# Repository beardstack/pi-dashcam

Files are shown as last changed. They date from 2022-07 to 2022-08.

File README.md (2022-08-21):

# pi-dashcam

This application follows the idea to setup an OpenSource dashcam
that can be run on a low-cost hardware like the Raspberry PI 3 A+
(but also as in my intial approach with a PI Zero).
Main purpose is to have a trustfull software following the requirements
of GDPR rules in Germany (DSGVO) to store data only temporary and save
video chunks only in cases of accidents/emergencies. Data can be stored
either on RPi SD Card or external USB device (automounted).
Triggering of video data storing can also be done via acceleration sensor.

This project comes with a custom camera and rpi case:
- there is a camera case for the RPi Camera V2 (e.g. NoIR edition)
- there is a RPi 3A+ fitting base, where an RTC-DS3231 can be inserted into
- there is a top covering case, where a breadboard plate of 5x7cm can be easily inserted
    (watch for the LED and Button cutouts!)

I created my own HAT for the Pi-3A+; pictures will follow...

## Requirements
- 32-Bit Raspberry Pi OS (necessary to run picamera v1!)
- min. 1 CPU
- min. 128MB RAM
- Pi Camera attached
- legacy camera support enabled in raspi-config
- RealTime-Clock RTC DS3231 (e.g.: https://www.amazon.de/dp/B077XN4LL4/ref=pe_27091401_487024491_TE_item )
- ADXL345 acceleration sensor (e.g.: https://www.amazon.de/dp/B09T376QXX/ref=pe_27091401_487027711_TE_SCE_dp_1 )
- 4 Buttons and one RGB-LED (e.g.: on amazon, the 12mm x 12mm x 7mm tactile push botton with 5 colours ...)
- 3D printed cases for camera and rpi from 3dprints subfolder
    (and obviously a 3dprinter or you know somebody ;) )
- Some Dashcam carrier for your car (e.g.: https://www.amazon.de/dp/B091BVDT56/ref=pe_27091401_487024491_TE_item )

A single core and 512MB of RAM is sufficient enough to have a 1080p 
dashcam running. However, I decided to stick to the Pi 3A+ in order to be
more powerfull for future approaches.
For a nicer interaction, this application allows the usage of buttons
to e.g. trigger a copy of all legal files at the moment (by default, the last
10 minutes) to a separate folder on the disk (or external, auto-mounted device),
to be available later.
In addition, three LEDs (or an RGB-LED) can be controlled; one is a Power-LED,
that indicates a running system (by default a slow heartbeat pulsar, can be adjusted via Button)
next to a Data-Copy-LED, that lights up when current legal video chunks are stored separately
and blinks for some seconds when that process is done, and finally an info LED
that e.g. shows, no external device mounted or the video capturing process stopped.

More parameter can be set (e.g. resolution, chunk size and count), but the
default values should optimal for the most cases (1080p, 10 video chunks of 60s).

Real-World approach is then to solder all com

For any question, do not hesitate to contact me.

Best regards,
Lars

___________________________
Default PIN scheme:

GND <--> Button Power            <--> Board Pin 11 (GPIO 17)

GND <--> Button Copy             <--> Board Pin 12 (GPIO 18)

GND <--> Button Stop             <--> Board Pin 13 (GPIO 27)

GND <--> Button Info control     <--> Board Pin 15 (GPIO 22)

GND <--> 220R <--> LED Data Copy <--> Board Pin 29 (GPIO 27)

GND <--> 220R <--> LED Power     <--> Board Pin 33 (GPIO 13)

GND <--> 220R <--> LED Power     <--> Board Pin 37 (GPIO 26)

ADXL345 VCC/3V3 <--> Board Pin 1 (3V3)

ADXL345 GND     <--> Board Pin 9 (GND)

ADXL345 CS      <--> Board Pin 24 (GPIO 8 / SPIO CE0)

ADXL345 SD0     <--> Board Pin 21 (GPIO 9 / SPIO MISO)

ADXL345 SDA     <--> Board Pin 19 (GPIO 10 / SPIO MOSI)

ADXL345 SCL     <--> Board Pin 23 (GPIO 11 / SPIO SCLK)

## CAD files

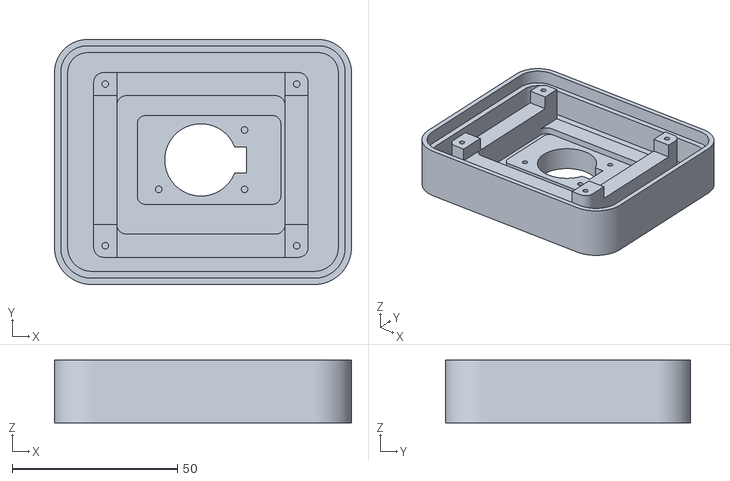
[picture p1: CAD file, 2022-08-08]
3dprints/Dashcam_Picase-Bottom.stl
90.0 x 74.2 x 19.0

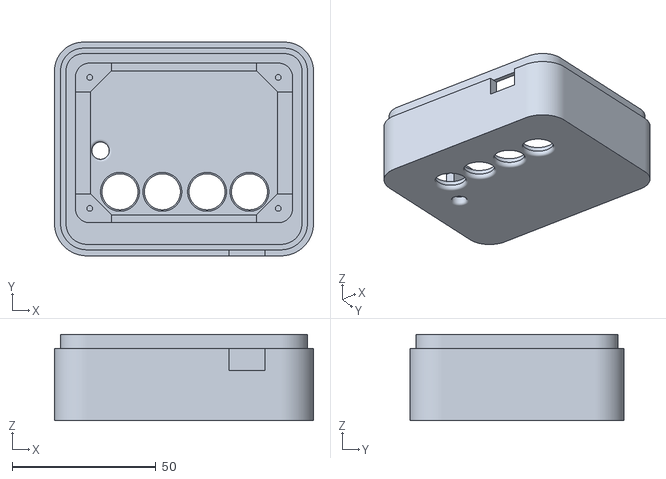
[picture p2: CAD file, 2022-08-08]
3dprints/Dashcam_Picase-Top.stl
90.0 x 74.2 x 30.0

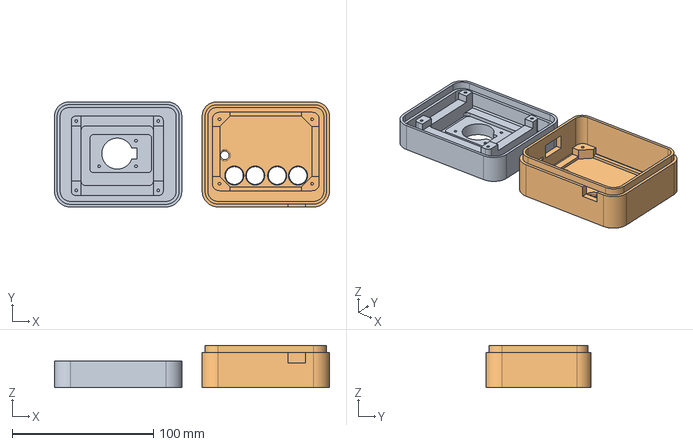
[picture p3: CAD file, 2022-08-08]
3dprints/Dashcam_Picase.FCStd
194.4 x 74.3 x 30.0 mm
Bottom
Top

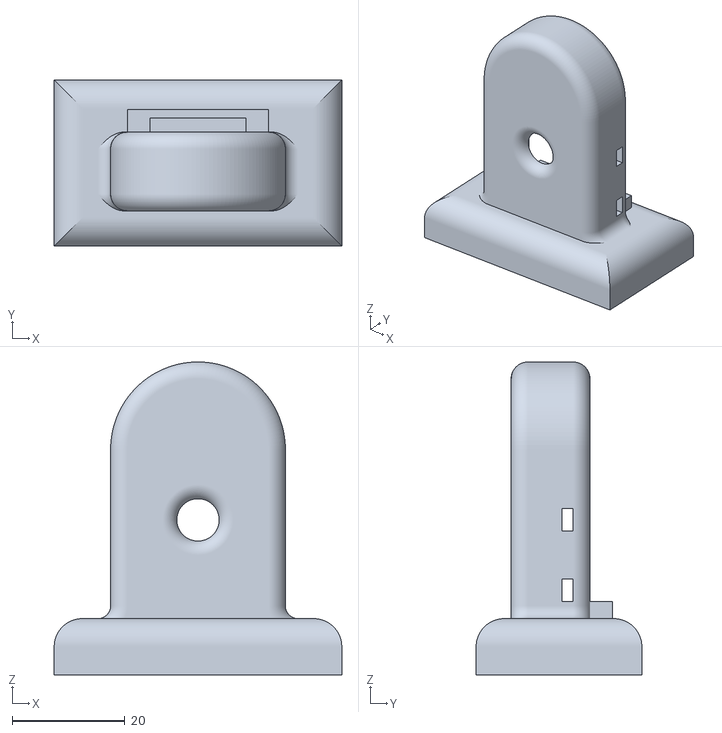
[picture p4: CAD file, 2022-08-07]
3dprints/PiCam_BaseCase.stl
51.0 x 29.4 x 55.5

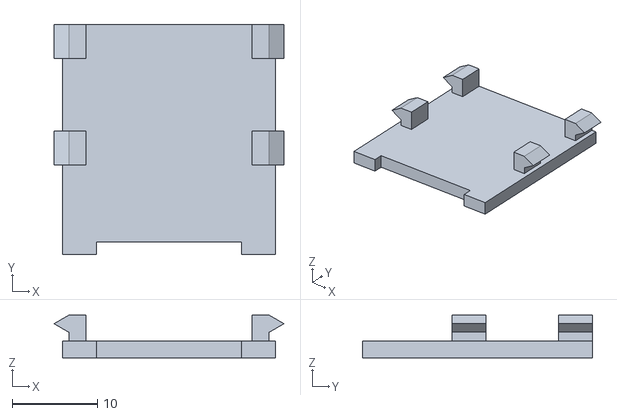
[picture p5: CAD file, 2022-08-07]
3dprints/PiCam_BaseCaseCover.stl
27.0 x 27.0 x 5.00

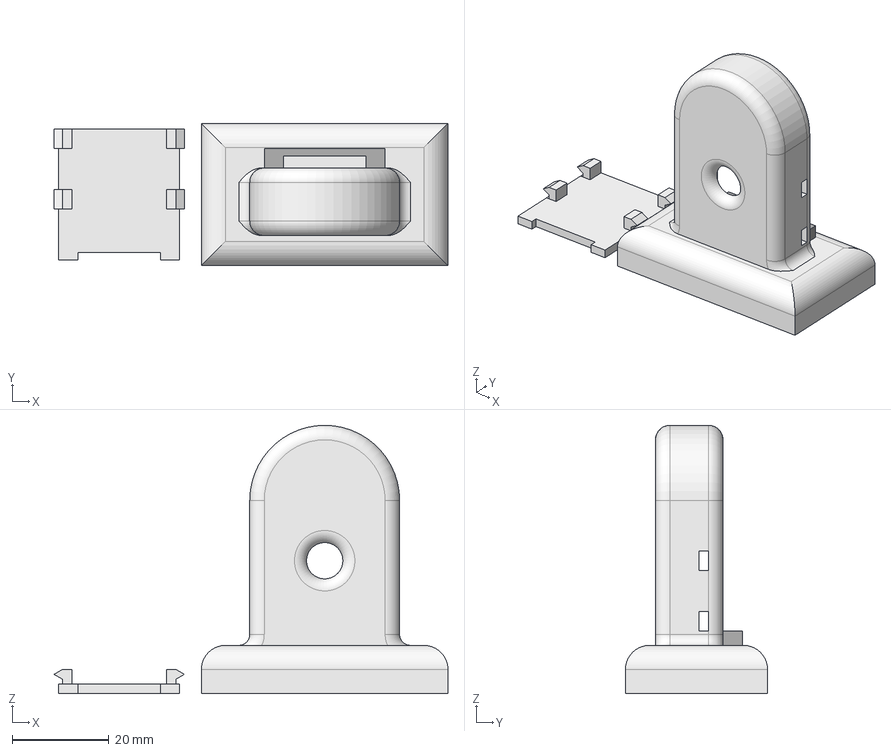
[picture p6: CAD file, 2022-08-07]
3dprints/Dashcam_Picamcase.FCStd
81.5 x 29.4 x 55.5 mm
Base
CameraCase
CameraNotch
Cover001
Hold
Hold001

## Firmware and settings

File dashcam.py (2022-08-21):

#!/usr/bin/env python3
import os
import shutil
import argparse
import picamera
from led import LED
from switch import Switch
from time import time, sleep
from threading import Thread, Lock
from random import randbytes
from movement import Adxl345Spi
from math import fabs


def get_usb_storage_device(desired_device=None):
    with open("/proc/partitions") as file:
        file.readline() #skip heading line
        file.readline() #skip empty line
        device_info = [
            [ item.strip() for item in line.strip().split() ]
            for line in file
        ]
        devices = [
            device[3]
            for device in device_info
            if len(device) >= 3 and device[0] in ("8", "259")
        ]
        primary_devices = [
            device[3]
            for device in device_info
            if len(device) >= 3 and device[0] in ("8", "259") and (int(device[1]) % 16) == 0
        ]

        block_class_path = "/sys/class/block"

        primary_usb_devices = [
            device
            for device in primary_devices
            if (
                os.path.islink(f"{block_class_path}/{device}") and
                os.path.realpath(f"{block_class_path}/{device}").find("/usb") > 0
            )
        ]

        usb_partitions = sorted(
            [
                partition
                for partition in devices
                for usb_device in primary_usb_devices
                if partition.startswith(usb_device) and usb_device != partition
            ],
            reverse=True #assuming the last partition of the last is correct
        )

        if desired_device is not None:
            if desired_device in usb_partitions:
                return desired_device
            return None
        return usb_partitions[0]

def mount_usb_device(device, id):
    mnt_path = f"/mnt/{id}"
    if not os.path.ismount(mnt_path):
        os.system(f"mkdir -p {mnt_path}")
        os.system(f"mount {device} {mnt_path}")
    return mnt_path



class Dashcam():
    def __init__(
            self, sequence_count=10, sequence_length=60, resolution=(1920, 1080),
            video_type="h264", video_name_prefix="video-dashcam", bitrate = 17000000,
            framerate=30, video_file_path="/opt/dashcam", pin_btn_pwr=11, pin_btn_cpy=12,
            pin_btn_stop=13, pin_btn_info=15, pin_led_cpy=29, pin_led_pwr=33,
            pin_led_info=37, led_pwr_dim_perc=5, g_force_limit=1.5, salt_bytes=4):
        self.pin_btn_cpy = pin_btn_cpy
        self.pin_btn_pwr = pin_btn_pwr
        self.pin_btn_info = pin_btn_info
        self.pin_btn_stop = pin_btn_stop
        self.pin_led_pwr = pin_led_pwr
        self.pin_led_cpy = pin_led_cpy
        self.pin_led_info = pin_led_info
        self.pin_led_pwr_dim_percent = led_pwr_dim_perc
        self.pin_blink_seconds = 2
        self.pin_blink_on_seconds = 0.1
        self.g_force_limit = g_force_limit

        self.video_sequence_seconds = sequence_length
        self.video_sequence_count = sequence_count
        self.video_resolution = resolution
        self.video_name_prefix = video_name_prefix
        self.video_file_path=video_file_path
        self.video_file_path_legal=f"{self.video_file_path}/legal"
        self.video_type = video_type if video_type in ("h264", "mjpeg") else "h264"
        self.video_bit_rate = bitrate
        self.video_frame_rate = framerate

        # using a salt to not eventually overwrite files
        # after an unexpected reboot in car; is like
        # a unique identifier for an ongoing record session
        self.video_name_salt = randbytes(salt_bytes).hex()

        self.LED_data = LED(self.pin_led_cpy)
        self.LED_power = LED(self.pin_led_pwr)
        self.LED_info = LED(self.pin_led_info)


        self.BTN_data = Switch(self.pin_btn_cpy)
        self.BTN_power = Switch(self.pin_btn_pwr)
        self.BTN_stop = Switch(self.pin_btn_stop)
        self.BTN_info = Switch(self.pin_btn_info)

        self.file_lock = Lock()
        self.camera_lock = Lock()

        self.adxl345 = Adxl345Spi()

        self.camera = picamera.PiCamera(
            resolution=self.video_resolution,
            framerate=self.video_frame_rate
        )
        self.camera_state = 0 #0: off, 1: turndown, 2: on
        self.info_led_state = 0
        self.segment_ctr = 0
        self.video_filename = ""

    def get_video_id(self):
        return self.video_name_salt

    def set_video_path(self, path):
        self.video_file_path = path
        self.video_file_path_legal = f"{self.video_file_path}/legal"

    def __del__(self):
        del self.LED_data, self.LED_power

    def _dashcam_video_thread(self):
        self.video_filename = (
            f"{self.video_name_prefix}_"
            f"{int(time())}-{self.video_name_salt}-"
            f"{self.segment_ctr}.{self.video_type}"
        )
        video_path = f"{self.video_file_path}/{self.video_filename}"
        print(f"Recording to '{video_path}'.")
        self.camera.start_recording(
            video_path, format=self.video_type, bitrate=self.video_bit_rate
        )
        self.camera.wait_recording(self.video_sequence_seconds)

        while self.camera_state > 1:
            self.segment_ctr += 1
            tmp_video_filename = (
                f"{self.video_name_prefix}_"
                f"{int(time())}-{self.video_name_salt}-"
                f"{self.segment_ctr}.{self.video_type}"
            )
            video_path = f"{self.video_file_path}/{tmp_video_filename}"
            print(f"Recording to '{video_path}'.")
            self.camera.split_recording(video_path)
            # as the copy thread callback might be a bit too fast,
            # we manage to set the final new filename AFTER the switch
            # which guarantees, that the file is really finished.
            self.video_filename = tmp_video_filename
            self.camera.wait_recording(self.video_sequence_seconds)
        self.camera.stop_recording()
        self.camera_state = 0


    def _dashcam_file_cleanup_thread(self):
        while True:
            self.file_lock.acquire()

            video_file_list = self.get_directory_file_list(
                self.video_file_path, self.video_type
            )
            video_file_list_legal = self.get_video_file_list_legal(
                video_file_list, buffer=1
            )

            delete_video_file_list = [
                video_file
                for video_file in video_file_list
                if video_file not in video_file_list_legal
            ]

            for del_video_file in delete_video_file_list:
                print(f"DELETE file '{del_video_file}'")
                try:
                    os.remove(f"{self.video_file_path}/{del_video_file}")
                except FileNotFoundError:
                    print(
                        f"WARNING! File '{self.video_file_path}/{del_video_file}'"
                        " is gone. Ignoreing file. Continue"
                    )

            self.file_lock.release()
            sleep(self.video_sequence_seconds)

    def _led_power_heartbeat(self, LED):
        LED.set_duty_cycle(self.pin_led_pwr_dim_percent)
        sleep(0.15)
        LED.set_duty_cycle(0)
        sleep(0.15)
        LED.set_duty_cycle(self.pin_led_pwr_dim_percent)
        sleep(0.2)
        LED.set_duty_cycle(0)

    def _dashcam_powerled_thread(self):
        round_cntr = 0
        round_time = 0.5

        LED_is_on = True

        LED_state_switch = {
            0: self.LED_info,
            2: self.LED_power
        }

        while True:
            if self.camera_state in LED_state_switch:
                LED = LED_state_switch[self.camera_state]
                if (self.info_led_state % 4) == 0 and (round_cntr % 60) == 0:
                    self._led_power_heartbeat(LED)
                elif (self.info_led_state % 4) == 1 and (round_cntr % 1) == 0:
                    self._led_power_heartbeat(LED)
                elif (self.info_led_state % 4) == 2:
                    if not LED_is_on:
                        LED.set_on()
                        LED.set_duty_cycle(self.pin_led_pwr_dim_percent)
                        LED_is_on = True
                else:
                    if LED_is_on:
                        LED.set_off()
                        LED_is_on = False
            elif self.camera_state == 1:
                if not LED_is_on:
                    self.LED_info.set_duty_cycle(self.pin_led_pwr_dim_percent)
                    LED_is_on = True
                else:
                    self.LED_info.set_off()
                    LED_is_on = False
            #sleep to make catch changes in e.g. info led status changes
            sleep(round_time)
            round_cntr += round_time

    def _g_force_surveillance(self):
        for _ in range(5):
            #cleanup at every start/coldstart (like at car ;) )
            x,y,z = self.adxl345.get_acceleration()
            sleep(1)
        while self.camera_state > 0:
            accl_xyz = self.adxl345.get_acceleration()
            if any(
                fabs(val) > self.g_force_limit
                for val in accl_xyz
            ):
                self.save_video_file_legal(self.LED_data)
            sleep(0.5)
        self.adxl345.stop()

    def get_directory_file_list(self, path, filetype):
        return [
            file
            for file in os.listdir(path)
            if (
                os.path.isfile(os.path.join(path,file)) and
                file.endswith(f'.{filetype}')
            )
        ]

    def get_video_file_list_legal(self, video_file_list, reverse=True, buffer=0):
        prefix_match_sorted_reduced_video_fileid_list = sorted(
            [
                file.removeprefix(
                    f"{self.video_name_prefix}_"
                ).removesuffix(
                    f'.{self.video_type}'
                )
                for file in video_file_list
                if file.startswith(f"{self.video_name_prefix}_")
            ], key = (
                lambda x: (
                    f"{int(x.split('-')[1] == self.video_name_salt)}{x}"
                )
            ), reverse=reverse
        )

        return [
                f"{self.video_name_prefix}_{fileid}.{self.video_type}"
                for fileid in prefix_match_sorted_reduced_video_fileid_list
            ][:self.video_sequence_count+buffer]

    def save_video_file_legal(self, LED):
        self.file_lock.acquire()
        LED.set_on()

        video_file_list_legal = self.get_video_file_list_legal(
            self.get_directory_file_list(
                self.video_file_path, self.video_type
            ), reverse=False
        )

        timestamp = int(time())
        legal_path = f"{self.video_file_path_legal}/{timestamp}_utc"
        os.makedirs(legal_path, exist_ok=True)

        current_video = self.video_filename
        is_active_saving = current_video in video_file_list_legal
        if is_active_saving:
            video_file_list_legal.remove(current_video)

        for video_file in video_file_list_legal:
            src = f"{self.video_file_path}/{video_file}"
            dst = f"{legal_path}/INCIDENT_{video_file}"
            print(f"Copy '{src}' to '{dst}'.")
            try:
                shutil.copyfile(src, dst)
            except FileNotFoundError:
                print(f"WARNING! File '{src}' is gone. Ignoreing file. Continue")
        while is_active_saving and self.video_filename == current_video:
            #waiting for current video to finish
            sleep(5)
        if is_active_saving:
            src = f"{self.video_file_path}/{current_video}"
            dst = f"{legal_path}/INCIDENT_{current_video}"
            print(f"Copy '{src}' to '{dst}'.")
            try:
                shutil.copyfile(src, dst)
            except FileNotFoundError:
                print(f"WARNING! File '{src}' is gone. Ignoreing file. Continue")

        print("Copy done.")

        for round in range(int(self.pin_blink_seconds / self.pin_blink_on_seconds)):
            if round % 2 == 0:
                LED.set_on()
            else:
                LED.set_off()
            sleep(self.pin_blink_on_seconds)

        LED.set_off()
        self.file_lock.release()

    def _button_copy_functor(self, input):
        if input == 0:
            self.save_video_file_legal(self.LED_data)

    def _button_start_functor(self, input):
        if input == 0:
            if self.camera_state == 0:
                self.camera_lock.acquire()
                self.camera_state = 2
                self.video_thread = Thread(target=self._dashcam_video_thread)
                self.g_force_thread = Thread(target=self._g_force_surveillance)
                self.video_thread.start()
                self.LED_power.set_duty_cycle(self.pin_led_pwr_dim_percent)
                self.g_force_thread.start()
                sleep(10) #mainly user notification via LED on
                self.camera_lock.release()

    def _button_stop_functor(self, input):
        if input == 0:
            if self.camera_state == 2:
                self.camera_lock.acquire()
                self.camera_state = 1
                self.LED_power.set_off()
                self.video_thread.join()
                self.g_force_thread.join()
                del self.video_thread
                del self.g_force_thread
                self.camera_lock.release()

    def _button_info_functor(self, input):
        if input == 0:
            # in order to keep numbers small and as we probably won't
            # have more than 100 blinking states, lets keep it 0 < x < 100 !
            self.info_led_state = (self.info_led_state + 1) % 100

    def do_warning(self):
        # just blink at info LED!
        # can be used when e.g. mountpoint is unavailable!!!
        for _ in range(10):
            self.LED_info.set_on()
            sleep(0.5)
            self.LED_info.set_off()
            sleep(0.5)


    def start(self):
        os.makedirs(self.video_file_path, exist_ok=True)
        os.makedirs(self.video_file_path_legal, exist_ok=True)

        self.power_led_thread = Thread(target=self._dashcam_powerled_thread)
        self.clean_thread = Thread(target=self._dashcam_file_cleanup_thread)

        self.BTN_data.set_functor(self._button_copy_functor)
        self.BTN_power.set_functor(self._button_start_functor)
        self.BTN_stop.set_functor(self._button_stop_functor)
        self.BTN_info.set_functor(self._button_info_functor)

        self.power_led_thread.start()
        self.clean_thread.start()

        self._button_start_functor(0)

    def join_clean_thread(self):
        self.clean_thread.join()

def main():
    parser = argparse.ArgumentParser(
        description="""DashCam-app following the German traffic and GDPR (DSGVO)
        laws. Is designed to work on any Raspberry PI that provides PiCamera
        library in Python; this fits basically for any 32-Bit driven RPI.
        Mainly used in combination with a RPI Zero W v1.1, which is totally
        sufficient for this purpose.
        Instead of a single, increasing video file, the input video stream is
        splitted into e.g. 60s video chunks; only the last e.g. 10 chunks are kept.
        This allows to have e.g. the last 10 minutes stored but also regularly cleaned
        in order to stay conform towards GDPR.
        There is a special incident procedure: when an attached button is pressed,
        the last e.g. 10 legal video chunks are separately stored and not cleaned
        to e.g. provide some legal information in any case of accident/emergency.
        In addition, two LEDs can be attached to print Power/Heartbeat information
        and to indicate the current, active data copy in any case of accident (this
        will only happen, when you press the button).
        """
    )

    parser.add_argument(
        "-s", "--video_chunk_duration", metavar="S", type=int, required=False,
        default=60, help="Length of a single stored video chunk."
    )
    parser.add_argument(
        "-c", "--video_chunk_count", metavar="C", type=int, required=False,
        default=10, help=(
            "Max. number of sequential video chunks that are stored in parallel"
            "on the disk; this correlates do GDPR laws."
        )
    )
    parser.add_argument(
        "-p", "--video_file_path", metavar="P", type=str, required=False,
        default="/opt/dashcam", help="Location to store dashcam video chunks"
    )
    parser.add_argument(
        "-f", "--video_file_prefix", metavar="F", type=str, required=False,
        default="video-dashcam", help=(
            "Filename prefix for the locally stored video file chunks"
        )
    )
    parser.add_argument(
        "-r", "--video_resolution", metavar="R", nargs=2, type=int, required=False,
        default=(1920, 1080), help="Length of a single stored video chunk."
    )
    parser.add_argument(
        "-br", "--video_bitrate", metavar="BR", type=int, required=False,
        default=7000000, help="Bitrate used to store videos."
    )
    parser.add_argument(
        "-vf", "--video_format", metavar="VF", type=str, required=False,
        default="h264", choices=("h264","mjpeg"),help="File format used to store videos."
    )
    parser.add_argument(
        "-lc", "--pin_led_copy", metavar="PLC", type=int, required=False,
        default=29, help="Pin number in GPIO.BOARD layout for a data-copy LED."
    )
    parser.add_argument(
        "-lp", "--pin_led_power", metavar="PLP", type=int, required=False,
        default=33, help="Pin number in GPIO.BOARD layout for a power LED."
    )
    parser.add_argument(
        "-li", "--pin_led_info", metavar="PLP", type=int, required=False,
        default=37, help="Pin number in GPIO.BOARD layout for an info LED."
    )
    parser.add_argument(
        "-bp", "--pin_button_power", metavar="PBP", type=int, required=False,
        default=11, help="Pin number in GPIO.BOARD layout for a start button."
    )
    parser.add_argument(
        "-bc", "--pin_button_copy", metavar="PBC", type=int, required=False,
        default=12, help="Pin number in GPIO.BOARD layout for a data copy button."
    )
    parser.add_argument(
        "-bs", "--pin_button_stop", metavar="PBS", type=int, required=False,
        default=13, help="Pin number in GPIO.BOARD layout for a stop button."
    )
    parser.add_argument(
        "-bi", "--pin_button_info", metavar="PBI", type=int, required=False,
        default=15, help="Pin number in GPIO.BOARD layout for a info-led control button."
    )
    parser.add_argument(
        "-d", "--pin_power_dim_percent", metavar="LPD", type=int, required=False,
        default=5, help="Percent dim for the Power LED; if it might be to bright."
    )
    parser.add_argument(
        "-g", "--g_force_limit", metavar="G", type=int, required=False, default=1.5,
        help="Threshold in terms of g-Force, when a data copy should be triggered."
    )
    parser.add_argument(
        "--external_usb_storage_device", metavar="DEVICE", type=str, required=False,
        help=(
            "Dev shortcut, e.g. sda1, for a partition/device you want to use as "
            "video storage. Will be directly written on it."
        )
    )

    args = parser.parse_args()

    video_chunk_duration = args.video_chunk_duration
    video_chunk_count = args.video_chunk_count
    video_file_path = args.video_file_path
    video_file_prefix = args.video_file_prefix
    video_resolution = args.video_resolution
    video_bitrate = args.video_bitrate
    video_format = args.video_format
    pin_button_copy = args.pin_button_copy
    pin_button_power = args.pin_button_power
    pin_button_stop = args.pin_button_stop
    pin_button_info = args.pin_button_info
    pin_led_power = args.pin_led_power
    pin_led_copy = args.pin_led_copy
    pin_led_info = args.pin_led_info
    pin_power_dim_percent = args.pin_power_dim_percent
    g_force_limit = args.g_force_limit
    usb_storage = args.external_usb_storage_device if hasattr(args,'external_usb_storage_device') else None


    dashcam = Dashcam(
        sequence_count=video_chunk_count, sequence_length=video_chunk_duration,
        resolution=video_resolution, video_type=video_format, bitrate=video_bitrate,
        video_name_prefix=video_file_prefix, video_file_path=video_file_path,
        pin_btn_cpy=pin_button_copy, pin_btn_pwr=pin_button_power,
        pin_btn_info=pin_button_info, pin_btn_stop=pin_button_stop,
        pin_led_cpy=pin_led_copy, pin_led_pwr=pin_led_power, pin_led_info=pin_led_info,
        led_pwr_dim_perc=pin_power_dim_percent, g_force_limit=g_force_limit
    )


    if usb_storage is not None:
        usb_device = get_usb_storage_device(usb_storage)
        if usb_device is not None:
            mount_path = mount_usb_device(f"/dev/{usb_device}", "dashcam-videodata")
            dashcam.set_video_path(mount_path)
        else:
            dashcam.do_warning()

    dashcam.start()
    dashcam.join_clean_thread()


if __name__=='__main__':
    main()

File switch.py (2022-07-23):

#!/usr/bin/env python3
"""
This module provides classes that relate/beling to the physical class of switches.
It can be used to easily read state from switches and transform physical states
into computer and human readable values.
Each switch instance will represent exactly one physical switch, so that
a certain switch pin related to exact one Switch.
The developer/user has to make sure, that there are no overlapping instances used...
In addition some basic functionality tests are provide as stand-alone script.
Classes:
    Switch
Functions:
    main
    class_Switch_test
    class_Switch_functor
"""
import RPi.GPIO as GPIO
GPIO.setmode(GPIO.BOARD)
class Switch:
    """
    Class to handle input/states of physical switches in GPIO.BOARD configuration.
    Each class instance controls exactly one switch.
    Can be used for simple buttons aswell as binary tilt-switches or binary
    vibrations switches.
    Make sure pins are mutual exclusiv!
    Methods:
        __init__(pin, freq, is_inverse)
        bouncetime()
        set_bouncetime(bouncetime)
        functor()
        set_functor(functor)
        edge()
        set_edge(edge)
        _update_callback()
        _press_btn(*args)
        default_functor()
    """
    def map_edge(edge):
        """
        Translate users integer input to return corresponding
        GPIO edge detection states (GPIO.RISING, GPIO.FALLING, GPIO.BOTH).
        GPIO.RISING means callback connected to an voltage increase
        (e.g. pull-down-resistor with button pressed)

        Keyword Arguments:
            edge -- Integer to set/update the wished edge detection mode.
                    >0: RISING, ==0: BOTH, <0: FALLING
        """
        if edge > 0:
            return GPIO.RISING
        if edge < 0:
            return  GPIO.FALLING
        return GPIO.BOTH
    def __init__(self, pin, functor=None, bouncetime=10, edge_detector=0, pud=1):
        """
        Constructor to create connect to a single switch; bouncetime, edge detection,
        PUD and a functor (what should be called on switch interaction) can be set.
        Mandatory to set is the pin to read the signal/state from a button.
        Keyword Arguments:
            pin -- the GPIO.BOARD pin
            functor -- function pointer, what should be called on switch action; (default: None -> calls default functor)
            bouncetime -- switch sleepyness, in which periods signals are ignored (do not react on button flickering) (default: 10)
            edge_detector -- integer to indicate on which kind of signal change (edge) to be listened to (default: 0 -> GPIO.BOTH)
            pud -- Integer to indicate if it is pull-up or pull-down resistor (default: 1 -> GPIO.PUD_UP)
        """
        self._pin = pin
        self._functor = functor if functor is not None else Switch.default_functor
        self._bouncetime = bouncetime
        self._edge = Switch.map_edge(edge_detector)
        self._pud = GPIO.PUD_UP if pud >= 0 else GPIO.PUD_DOWN
        GPIO.setup(self._pin, GPIO.IN, pull_up_down=self._pud)
        self._update_callback()
    def pud(self):
        """
        Return the PUD (pull up or down) resistor state of switch.
        Cannot be set, only during creation of switch instance.

        Returns: GPIO.PUD_UP or GPIO.PUD_DOWN
        """
        return self._pud
    def bouncetime(self):
        """
        Return the currently used bouncetime; bouncetime indicates how fast a signal change (edge)
        should/can trigger the callback function.
        Returns: bouncetime -- integer
        """
        return self._bouncetime
    def set_bouncetime(self, bouncetime):
        """
        Override the currently used bouncetime; will trigger an update of the callback function
        by removing and adding (with new values) an event_detection to button signal pin.
        Bouncetime indicates how fast a signal change (edge) should/can trigger the callback function.
        Keyword Arguments:
            bouncetime -- switch sleepyness, after which time periods signals are recognised.
        """
        self._bouncetime = bouncetime
        self._update_callback()
    def functor(self):
        """
        Returns the currently used functor that is used within callback triggering of the switch.
        No real usage except comporing somewhere maybe ...
        Returns: functor -- function pointer
        """
        return self._functor
    def set_functor(self, functor):
        """
        Set the functor, function pointer that is used during the callback triggering; the input
        for the functor is the current state of the button when pressed/released (typical: 0,1).
        Allows the overriding for general purpose usage.
        Keyword Arguments:
            functor -- function pointer
        """
        self._functor = functor
    def edge(self):
        """
        Returns the currently used edge detection for the switch.
        Indicates if it is configured to listen on GPIO.RISING, -.FALLING or -.BOTH.
        Returns: GPIO.BOTH, GPIO.FALLING or GPIO.RISING
        """
        return self._edge
    def set_edge(self, edge_detector):
        """
        Allows overwriting of the edge detectiong during the callback triggering.
        Based on the PUD resitor type, we can listen to a falling, rising or both
        voltage changes.
        Input is an integer, that is mapped accordingly to the three states
        RISING, BOTH, FALLING (>0, ==0 , <0).
        Keyword Arguments:
            edge_detector  -- integer, where the sign indicates for the edge_detection
                                (RISING, BOTH, FALLING)
        """
        self._edge = Switch.map_edge(edge_detector)
        self._update_callback()
    def _update_callback(self):
        """
        Internal function that is used to update the callback by removing and adding
        the event_detection with adjusted values.
        Is used in order to included changes on edge or bouncetime.
        """
        GPIO.remove_event_detect(self._pin)
        GPIO.add_event_detect(self._pin, self._edge, callback=self._press_btn, bouncetime=self._bouncetime)
    def _press_btn(self, *args):
        """
        Internal callback function that is used when a switch is triggered;
        generically makes use of the given functor (default or adjusted by needs);
        the current button/pin state is provided to the functor.
        Keyword Arguments:
            args -- generic arguments from the callback, currently not used.
        """
        self._functor(GPIO.input(self._pin))
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

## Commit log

2022-07-24 Reverse order for file copy. Copying current written file as last one allows to gather more video material (e.g. something is cached and not yet written!)
    [dashcam.py]
2022-07-24 Fix video type in argparse. Make bitrate actually used.
    [dashcam.py]
2022-07-27 Adding initial base case for the raspberry pi camera v2. Cover for the case needs to be added.
    [PiCam_BaseCase.stl]
2022-07-29 Finalising the frontwindow pi came base with its base for a window mount and a cover to protect the camera itself.
    [PiCam_BaseCase.stl, PiCam_BaseCaseCover.stl]
2022-07-29 include original freecad modelling for future changes, e.g. like a mount for IR leds and night vision
    [Dashcam_Picamcase.FCStd]
2022-07-31 Updating cover for better fit with camera and updating notch for easy cable input.
    [Dashcam_Picamcase.FCStd, PiCam_BaseCase.stl, PiCam_BaseCaseCover.stl]
2022-08-07 Setup initial RPi 3A case with cutouts for 3 buttons, LED in upper case part and RTC in lower case part.
    [Dashcam_Picase-Bottom.stl, Dashcam_Picase-Top.stl, Dashcam_Picase.FCStd]
2022-08-07 Updating cases for raspberry pi to handle more buttons in a nicer layout.
    [Dashcam_Picamcase.FCStd, Dashcam_Picase-Bottom.stl, Dashcam_Picase-Top.stl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]
2022-08-08 Updating case after first printing a bit.
    [Dashcam_Picase-Bottom.stl, Dashcam_Picase-Top.stl, Dashcam_Picase.FCStd]
2022-08-10 Setup functionality to handle more buttons and LEDs. There is now a button for starting+stopping recording. In addition, slow heartbeat is default mode for blinking. Blinking can now be adjusted via 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
2022-08-10 Add some mount utility, in order to store videos on external USB devices. automount if program parameter is provided. Fixing some other stuff in install skript
    [dashcam.py]
2022-08-11 Fix issue of partial video capturing (delayed writing to drive) in incident case. Now process is waiting for the finish of the file capturing.
    Setup a timestap folder utc for each incident individually in order to make it faster accessable afterwards.
    [dashcam.py]
2022-08-11 Small fix in order to ensure, that the instance wide filename is changed, when the new video already started. This makes sure, copy over is really done only when the cam is not anymore writing to tha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
    [dashcam.py]
2022-08-11 Fix problem with not being active (right after video split) and thus file is already changed.
    [dashcam.py]
2022-08-21 Setup adxl345 sensor initiall for dashcam.
2022-08-21 Update the documentation to current status
